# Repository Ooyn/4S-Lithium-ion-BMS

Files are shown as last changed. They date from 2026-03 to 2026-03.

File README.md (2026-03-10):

# 4S-Lithium-ion-BMS
This repository contains the schematic and design files for a custom 4S Lithium-ion Battery Management System (BMS). Utilizing an active shunt architecture, this project is designed to safely charge and balance a four-cell series battery pack. The system features a primary power input stage protected against reverse polarity by a MOSFET, followed by an LM317 adjustable linear voltage regulator. This regulator, paired with a potentiometer and filtering capacitors, allows for precise tuning of the total pack charging voltage, typically targeted at 16.8V.

The core of the balancing circuitry consists of four identical active shunt modules, with one dedicated to monitoring each individual cell. Each module employs a TL431LP precision voltage reference, configured with a resistor divider network. This setup allows the TL431LP to act as a highly accurate analog comparator, continuously monitoring the specific voltage of its connected cell as the entire battery pack charges.

As the voltage across an individual cell rises and hits the critical 4.2V maximum threshold, its corresponding TL431LP begins to conduct. This conduction pulls current from the base of a paired BD140 PNP power transistor, activating it to open a parallel bypass path. Consequently, the charging current is successfully routed around the fully charged cell and safely dissipated as heat through a series array of 1N4007 diodes.

Dedicated LEDs on each module provide immediate visual feedback when this bypass circuit is active. By seamlessly shunting current away from fully charged cells, this custom BMS prevents overvoltage degradation while maintaining the continuous series charging loop. This mechanism ensures that any remaining under-charged cells can safely reach their maximum capacity without risking damage to the rest of the pack.



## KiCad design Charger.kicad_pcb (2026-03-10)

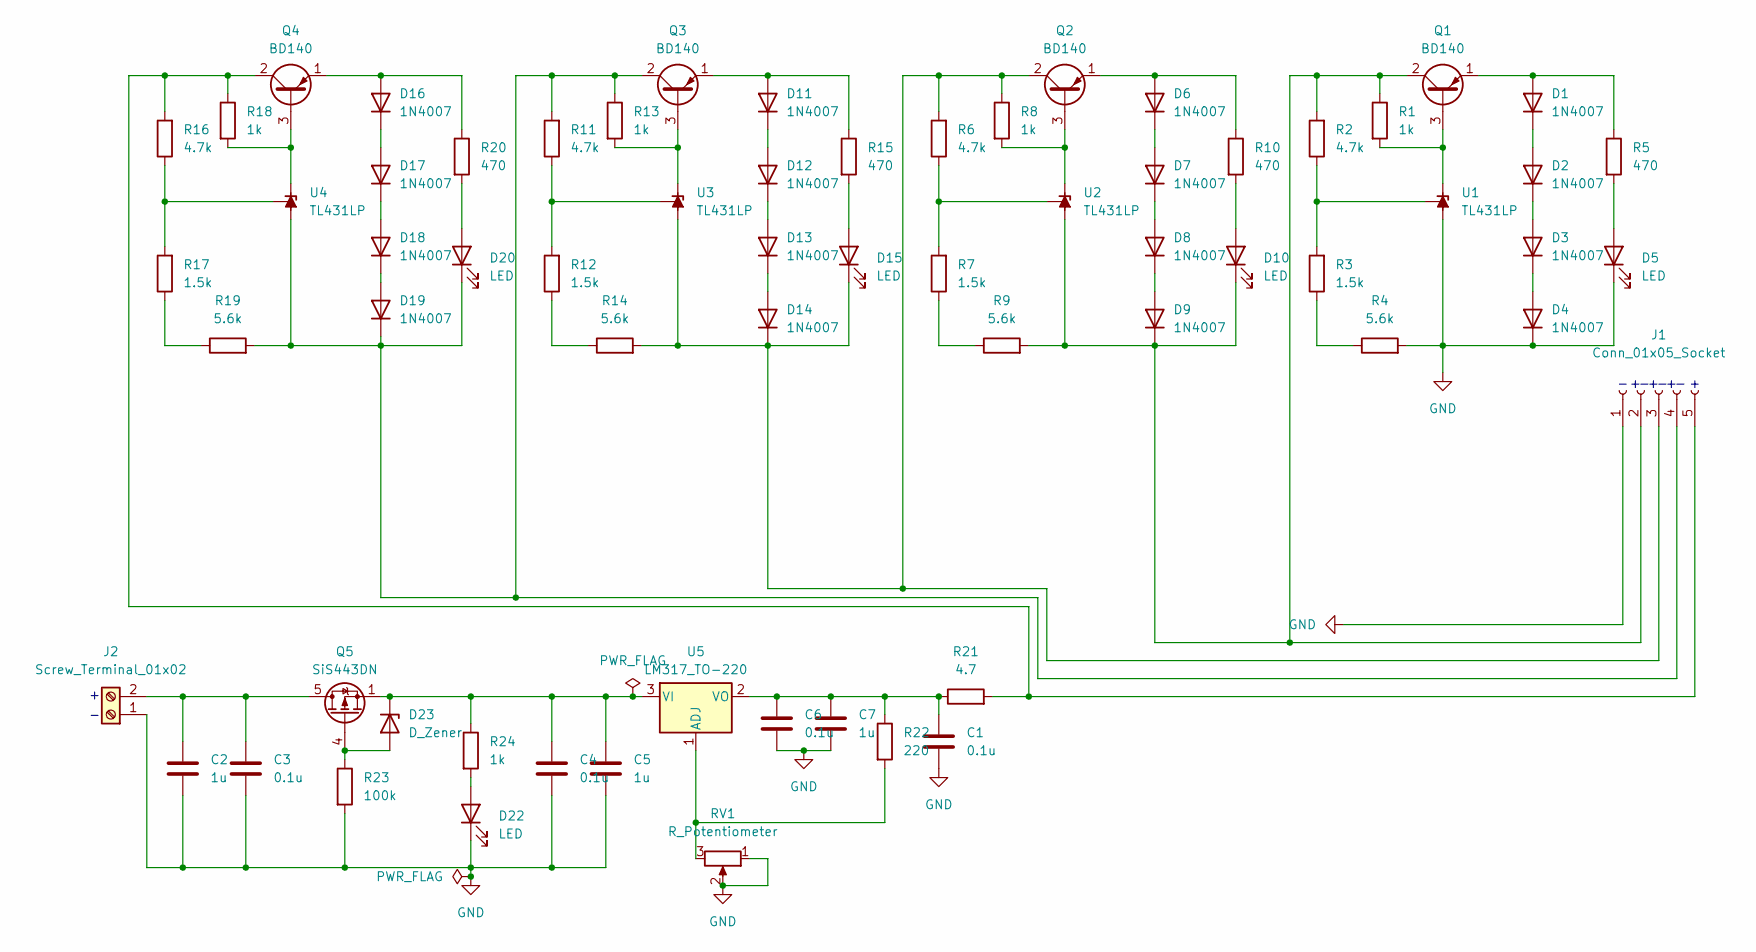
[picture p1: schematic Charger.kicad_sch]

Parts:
C1: 0.1u; C_Disc_D7.5mm_W2.5mm_P5.00mm
C2, C5, C7: 1u; C_Disc_D5.0mm_W2.5mm_P5.00mm
C3, C4, C6: 0.1u; C_Disc_D5.0mm_W2.5mm_P5.00mm
D1, D2, D3, D4, D6, D7, D8, D9, D11, D12, D13, D14, D16, D17, D18, D19: 1N4007; D_DO-41_SOD81_P7.62mm_Horizontal
D5, D10, D15, D20, D22: LED; LED_D3.0mm_Clear
D23: D_Zener; D_DO-35_SOD27_P7.62mm_Horizontal
J1: Conn_01x05_Socket; Molex_PicoBlade_53047-0510_1x05_P1.25mm_Vertical
J2: Screw_Terminal_01x02; TerminalBlock_Xinya_XY308-2.54-2P_1x02_P2.54mm_Horizontal
Q1, Q2, Q3, Q4: BD140; TO-126-3_Horizontal_TabDown
Q5: SiS443DN; Vishay_PowerPAK_1212-8_Single
R1, R8, R13, R18, R24: 1k; R_Axial_DIN0204_L3.6mm_D1.6mm_P5.08mm_Horizontal
R2, R6, R11, R16: 4.7k; R_Axial_DIN0204_L3.6mm_D1.6mm_P5.08mm_Horizontal
R3, R7, R12, R17: 1.5k; R_Axial_DIN0204_L3.6mm_D1.6mm_P5.08mm_Horizontal
R4, R9, R14, R19: 5.6k; R_Axial_DIN0204_L3.6mm_D1.6mm_P5.08mm_Horizontal
R5, R10, R15, R20: 470; R_Axial_DIN0204_L3.6mm_D1.6mm_P5.08mm_Horizontal
R21: 4.7; R_Axial_DIN0204_L3.6mm_D1.6mm_P5.08mm_Horizontal
R22: 220; R_Axial_DIN0204_L3.6mm_D1.6mm_P5.08mm_Horizontal
R23: 100k; R_Axial_DIN0204_L3.6mm_D1.6mm_P5.08mm_Horizontal
RV1: R_Potentiometer; Potentiometer_Bourns_3296W_Vertical
U1, U2, U3, U4: TL431LP; TO-92L_HandSolder
U5: LM317_TO-220; TO-220-3_Horizontal_TabDown

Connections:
GND: C1.2, C2.2, C3.2, C4.1, C5.1, C6.1, C7.1, D4.1 (K), D5.1 (K), D22.1 (K), J1.1, J2.1, R4.2, R23.2, RV1.1, RV1.2, U1.2 (A)
unnamed: D1.2 (A), Q1.1 (E), R5.1
unnamed: D1.1 (K), D2.2 (A)
unnamed: D2.1 (K), D3.2 (A)
unnamed: D3.1 (K), D4.2 (A)
unnamed: D5.2 (A), R5.2
unnamed: D6.2 (A), Q2.1 (E), R10.1
unnamed: D6.1 (K), D7.2 (A)
unnamed: D7.1 (K), D8.2 (A)
unnamed: D8.1 (K), D9.2 (A)
unnamed: D10.2 (A), R10.2
unnamed: D9.1 (K), D10.1 (K), J1.2, Q1.2 (C), R1.1, R2.2, R9.2, U2.2 (A)
unnamed: D11.2 (A), Q3.1 (E), R15.1
unnamed: D11.1 (K), D12.2 (A)
unnamed: D12.1 (K), D13.2 (A)
unnamed: D13.1 (K), D14.2 (A)
unnamed: D14.1 (K), D15.1 (K), J1.3, Q2.2 (C), R6.2, R8.1, R14.2, U3.2 (A)
unnamed: D15.2 (A), R15.2
unnamed: D16.2 (A), Q4.1 (E), R20.1
unnamed: D16.1 (K), D17.2 (A)
unnamed: D17.1 (K), D18.2 (A)
unnamed: D18.1 (K), D19.2 (A)
unnamed: D19.1 (K), D20.1 (K), J1.4, Q3.2 (C), R11.2, R13.1, R19.2, U4.2 (A)
unnamed: D20.2 (A), R20.2
unnamed: D22.2 (A), R24.2
unnamed: D23.2 (A), Q5.4 (G), R23.1
unnamed: C4.2, C5.2, D23.1 (K), Q5.1 (S), Q5.2 (S), Q5.3 (S), R24.1, U5.3 (VI)
unnamed: J1.5, Q4.2 (C), R16.2, R18.1, R21.2
unnamed: C2.1, C3.1, J2.2, Q5.5 (D)
unnamed: Q1.3 (B), R1.2, U1.3 (K)
unnamed: Q2.3 (B), R8.2, U2.3 (K)
unnamed: Q3.3 (B), R13.2, U3.3 (K)
unnamed: Q4.3 (B), R18.2, U4.3 (K)
unnamed: R3.1, R4.1
unnamed: R7.1, R9.1
unnamed: R12.1, R14.1
unnamed: R17.1, R19.1
unnamed: R2.1, R3.2, U1.1 (REF)
unnamed: R6.1, R7.2, U2.1 (REF)
unnamed: R11.1, R12.2, U3.1 (REF)
unnamed: R16.1, R17.2, U4.1 (REF)
unnamed: R22.2, RV1.3, U5.1 (ADJ)
unnamed: C1.1, C6.2, C7.2, R21.1, R22.1, U5.2 (VO)

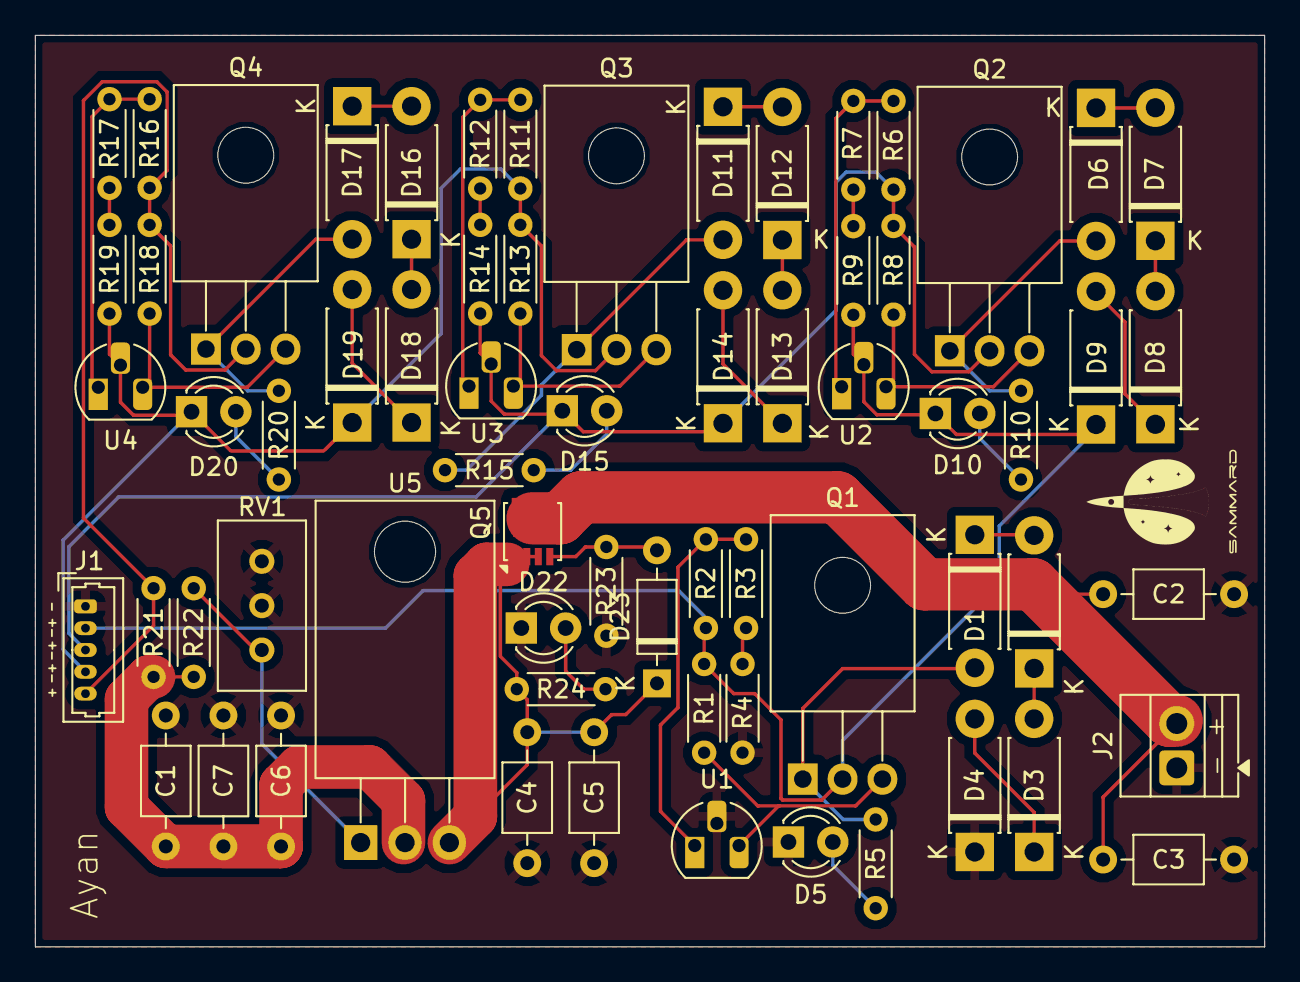
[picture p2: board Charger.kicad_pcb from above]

Board: 2 copper layers, 70.4 x 52.2 mm, 66 parts (0 on the bottom side), 43 nets.
